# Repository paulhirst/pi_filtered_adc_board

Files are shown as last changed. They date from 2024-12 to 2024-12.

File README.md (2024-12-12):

# pi_filtered_adc_board
PCB for R-pi with 8-channel ADC with 2nd order active low pass filters.

This is a KiCad schematic and PCB design for a PCB that connects to a
Raspberry Pi via the 40-pin GPIO connector. The board hosts an 8-channel
ADC connected vi SPI to the R-Pi, with single supply op-amps and passive
component positions to implement a 2nd-order Butterworth low-pass filter
on each channel. 

A convenient pin-grid is supplies to connect the ADC to the SPI0 or SPI1 
interfaces on the R-Pi, or to connect the SPI interface of the ADC to any
R-Pi GPIO pins.

If you don't want to implement 2nd order filters on the inputs, you can simply
omit the filter capacitors and replace resistors with wire links to use the 
opamps and simple buffers, or you could place resistors to set gain.

Resistor placements are provided to allow for example forming a potential 
divider with an on-board resistor and an off-board thermistor. The on-board
resistor placements can be shorted to provide +3.3 or +5v (selectable) on the
inputs D connector, providing for either 2 or 3-pin inputs (ie resistor or
potentiometer style inputs).

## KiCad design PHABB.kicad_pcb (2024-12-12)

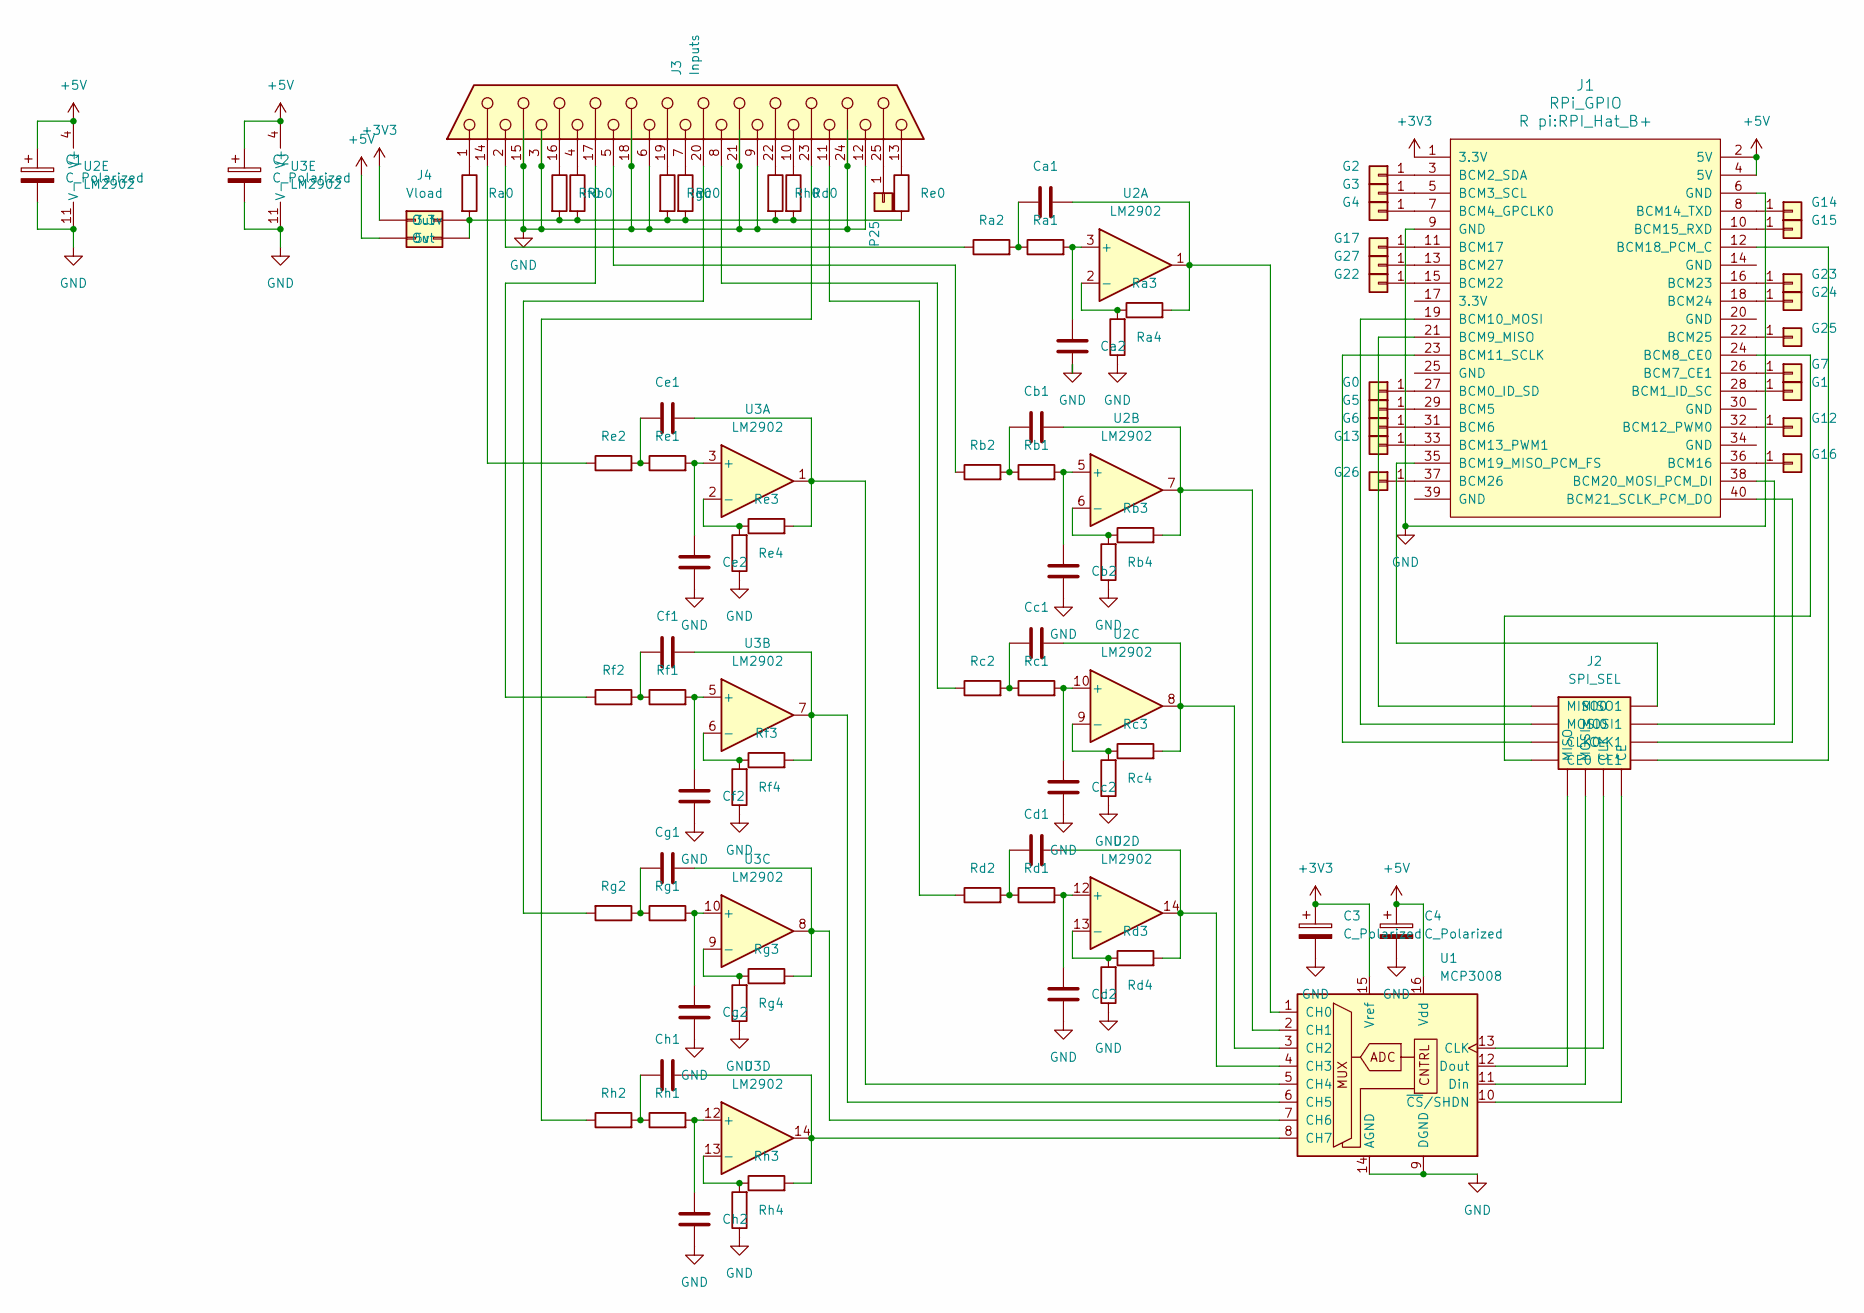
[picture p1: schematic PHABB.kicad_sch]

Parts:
C1, C2, C3, C4: C_Polarized; CP_Radial_D5.0mm_P2.50mm
Ca1, Ca2: C; C_Disc_D7.5mm_W5.0mm_P10.00mm
Cb1, Cb2: C; C_Disc_D7.5mm_W5.0mm_P10.00mm
Cc1, Cc2: C; C_Disc_D7.5mm_W5.0mm_P10.00mm
Cd1, Cd2: C; C_Disc_D7.5mm_W5.0mm_P10.00mm
Ce1, Ce2: C; C_Disc_D7.5mm_W5.0mm_P10.00mm
Cf1, Cf2: C; C_Disc_D7.5mm_W5.0mm_P10.00mm
Cg1, Cg2: C; C_Disc_D7.5mm_W5.0mm_P10.00mm
Ch1, Ch2: C; C_Disc_D7.5mm_W5.0mm_P10.00mm
G0: GPIO0; PinHeader_1x01_P2.54mm_Vertical
G1: GPIO1; PinHeader_1x01_P2.54mm_Vertical
G2: GPIO2; PinHeader_1x01_P2.54mm_Vertical
G3: GPIO3; PinHeader_1x01_P2.54mm_Vertical
G4: GPIO4; PinHeader_1x01_P2.54mm_Vertical
G5: GPIO5; PinHeader_1x01_P2.54mm_Vertical
G6: GPIO6; PinHeader_1x01_P2.54mm_Vertical
G7: GPIO07; PinHeader_1x01_P2.54mm_Vertical
G12: GPIO12; PinHeader_1x01_P2.54mm_Vertical
G13: GPIO13; PinHeader_1x01_P2.54mm_Vertical
G14: GPIO14; PinHeader_1x01_P2.54mm_Vertical
G15: GPIO15; PinHeader_1x01_P2.54mm_Vertical
G16: GPIO16; PinHeader_1x01_P2.54mm_Vertical
G17: GPIO17; PinHeader_1x01_P2.54mm_Vertical
G22: GPIO22; PinHeader_1x01_P2.54mm_Vertical
G23: GPIO23; PinHeader_1x01_P2.54mm_Vertical
G24: GPIO24; PinHeader_1x01_P2.54mm_Vertical
G25: GPIO25; PinHeader_1x01_P2.54mm_Vertical
G26: GPIO26; PinHeader_1x01_P2.54mm_Vertical
G27: GPIO27; PinHeader_1x01_P2.54mm_Vertical
J1: RPi_GPIO; RPI_Hat_B+
J2: SPI_SEL; 3x4 pingrid
J3: Inputs; DSUB-25_Female_Horizontal_P2.77x2.54mm_EdgePinOffset9.40mm
J4: Vload; PinHeader_2x02_P2.54mm_Vertical
P25: GPIO2; PinHeader_1x01_P2.54mm_Vertical
Ra0, Ra1, Ra2, Ra3, Ra4: R; R_Axial_DIN0204_L3.6mm_D1.6mm_P7.62mm_Horizontal
Rb0, Rb1, Rb2, Rb3, Rb4: R; R_Axial_DIN0204_L3.6mm_D1.6mm_P7.62mm_Horizontal
Rc0, Rc1, Rc2, Rc3, Rc4: R; R_Axial_DIN0204_L3.6mm_D1.6mm_P7.62mm_Horizontal
Rd0, Rd1, Rd2, Rd3, Rd4: R; R_Axial_DIN0204_L3.6mm_D1.6mm_P7.62mm_Horizontal
Re0, Re1, Re2, Re3, Re4: R; R_Axial_DIN0204_L3.6mm_D1.6mm_P7.62mm_Horizontal
Rf0, Rf1, Rf2, Rf3, Rf4: R; R_Axial_DIN0204_L3.6mm_D1.6mm_P7.62mm_Horizontal
Rg0, Rg1, Rg2, Rg3, Rg4: R; R_Axial_DIN0204_L3.6mm_D1.6mm_P7.62mm_Horizontal
Rh0, Rh1, Rh2, Rh3, Rh4: R; R_Axial_DIN0204_L3.6mm_D1.6mm_P7.62mm_Horizontal
U1: MCP3008; DIP-16_W7.62mm
U2, U3: LM2902; DIP-14_W7.62mm

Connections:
+3V3: C3.1, J1.1 (3.3V), J4.1 (3.3v), U1.15 (Vref)
+5V: C1.1, C2.1, C4.1, J1.2 (5V), J1.4 (5V), J4.3 (5v), U1.16 (Vdd), U2.4 (V+), U3.4 (V+)
GND: C1.2, C2.2, C3.2, C4.2, Ca2.2, Cb2.2, Cc2.2, Cd2.2, Ce2.2, Cf2.2, Cg2.2, Ch2.2, J1.6 (GND), J1.9 (GND), J3.3, J3.6, J3.9, J3.12, J3.15, J3.18, J3.21, J3.24, Ra4.1, Rb4.1, Rc4.1, Rd4.1, Re4.1, Rf4.1, Rg4.1, Rh4.1, U1.9 (DGND), U1.14 (AGND), U2.11 (V-), U3.11 (V-)
unnamed: Ca1.1, Ra1.1, Ra2.2
unnamed: Cb1.1, Rb1.1, Rb2.2
unnamed: Cc1.1, Rc1.1, Rc2.2
unnamed: Cd1.1, Rd1.1, Rd2.2
unnamed: Ce1.1, Re1.1, Re2.2
unnamed: Cf1.1, Rf1.1, Rf2.2
unnamed: Cg1.1, Rg1.1, Rg2.1
unnamed: Ch1.1, Rh1.1, Rh2.2
unnamed: G0.1, J1.27 (BCM0_ID_SD)
unnamed: G1.1, J1.28 (BCM1_ID_SC)
unnamed: G2.1, J1.3 (BCM2_SDA)
unnamed: G3.1, J1.5 (BCM3_SCL)
unnamed: G4.1, J1.7 (BCM4_GPCLK0)
unnamed: G5.1, J1.29 (BCM5)
unnamed: G6.1, J1.31 (BCM6)
unnamed: G7.1, J1.26 (BCM7_CE1)
unnamed: G12.1, J1.32 (BCM12_PWM0)
unnamed: G13.1, J1.33 (BCM13_PWM1)
unnamed: G14.1, J1.8 (BCM14_TXD)
unnamed: G15.1, J1.10 (BCM15_RXD)
unnamed: G16.1, J1.36 (BCM16)
unnamed: G17.1, J1.11 (BCM17)
unnamed: G22.1, J1.15 (BCM22)
unnamed: G23.1, J1.16 (BCM23)
unnamed: G24.1, J1.18 (BCM24)
unnamed: G25.1, J1.22 (BCM25)
unnamed: G26.1, J1.37 (BCM26)
unnamed: G27.1, J1.13 (BCM27)
unnamed: J1.24 (BCM8_CE0), J2.4 (CE0)
unnamed: J1.21 (BCM9_MISO), J2.1 (MISO0)
unnamed: J1.19 (BCM10_MOSI), J2.2 (MOSI0)
unnamed: J1.23 (BCM11_SCLK), J2.3 (CLK0)
unnamed: J1.12 (BCM18_PCM_C), J2.8 (CE1)
unnamed: J1.35 (BCM19_MISO_PCM_FS), J2.5 (MISO1)
unnamed: J1.38 (BCM20_MOSI_PCM_DI), J2.6 (MOSI1)
unnamed: J1.40 (BCM21_SCLK_PCM_DO), J2.7 (CLK1)
unnamed: J2.12 (CE), U1.10 (~CS/SHDN)
unnamed: J2.11 (CLK), U1.13 (CLK)
unnamed: J2.9 (MISO), U1.12 (Dout)
unnamed: J2.10 (MOSI), U1.11 (Din)
unnamed: J3.14, Re2.1
unnamed: J3.16, Rf0.1
unnamed: J3.17, Rf2.1
unnamed: J3.19, Rg0.1
unnamed: J3.20, Rg2.2
unnamed: J3.22, Rh0.1
unnamed: J3.23, Rh2.1
unnamed: J3.25, P25.1
unnamed: J3.1, Ra0.1
unnamed: J3.2, Ra2.1
unnamed: J3.4, Rb0.1
unnamed: J3.5, Rb2.1
unnamed: J3.7, Rc0.1
unnamed: J3.8, Rc2.1
unnamed: J3.10, Rd0.1
unnamed: J3.11, Rd2.1
unnamed: J3.13, Re0.1
unnamed: J4.2 (Out), J4.4 (Out), Ra0.2, Rb0.2, Rc0.2, Rd0.2, Re0.2, Rf0.2, Rg0.2, Rh0.2
unnamed: Ca1.2, Ra3.2, U1.1 (CH0), U2.1
unnamed: Cb1.2, Rb3.2, U1.2 (CH1), U2.7
unnamed: Cc1.2, Rc3.2, U1.3 (CH2), U2.8
unnamed: Cd1.2, Rd3.2, U1.4 (CH3), U2.14
unnamed: Ce1.2, Re3.2, U1.5 (CH4), U3.1
unnamed: Cf1.2, Rf3.2, U1.6 (CH5), U3.7
unnamed: Cg1.2, Rg3.2, U1.7 (CH6), U3.8
unnamed: Ch1.2, Rh3.2, U1.8 (CH7), U3.14
unnamed: Ca2.1, Ra1.2, U2.3 (+)
unnamed: Ra3.1, Ra4.2, U2.2 (-)
unnamed: Cb2.1, Rb1.2, U2.5 (+)
unnamed: Rb3.1, Rb4.2, U2.6 (-)
unnamed: Cc2.1, Rc1.2, U2.10 (+)
unnamed: Rc3.1, Rc4.2, U2.9 (-)
unnamed: Cd2.1, Rd1.2, U2.12 (+)
unnamed: Rd3.1, Rd4.2, U2.13 (-)
unnamed: Ce2.1, Re1.2, U3.3 (+)
unnamed: Re3.1, Re4.2, U3.2 (-)
unnamed: Cf2.1, Rf1.2, U3.5 (+)
unnamed: Rf3.1, Rf4.2, U3.6 (-)
unnamed: Cg2.1, Rg1.2, U3.10 (+)
unnamed: Rg3.1, Rg4.2, U3.9 (-)
unnamed: Ch2.1, Rh1.2, U3.12 (+)
unnamed: Rh3.1, Rh4.2, U3.13 (-)

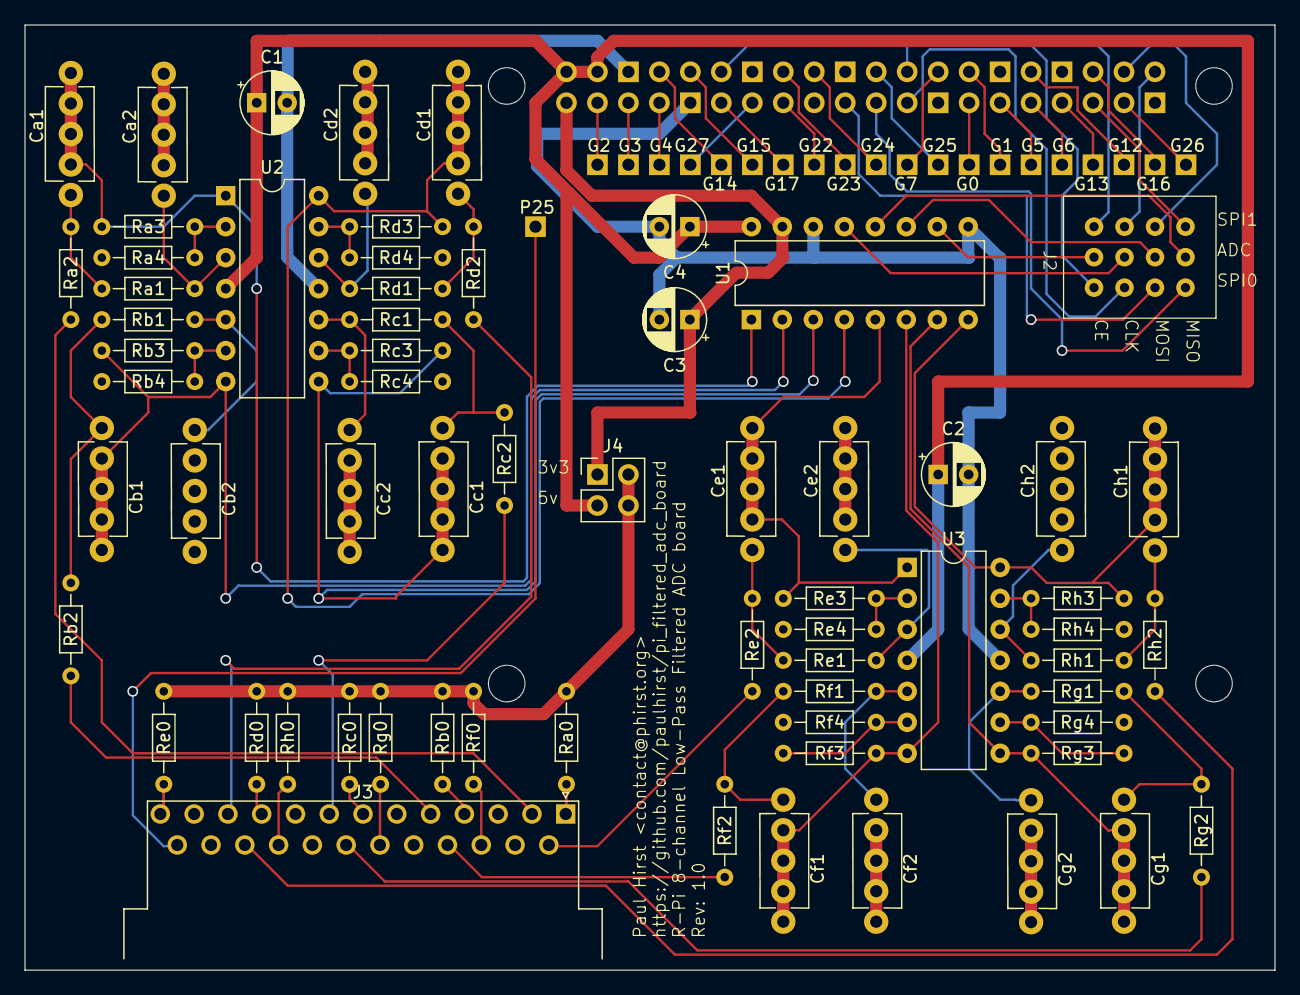
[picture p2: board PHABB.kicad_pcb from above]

Board: 2 copper layers, 102.5 x 77.5 mm, 88 parts (0 on the bottom side), 85 nets.
